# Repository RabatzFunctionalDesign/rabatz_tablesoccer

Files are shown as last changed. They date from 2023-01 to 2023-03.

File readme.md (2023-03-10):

# Rabatz Table Soccer

*Production files and assembly instructions*

## Project links

- [Design reference](https://www.rabatzdesign.com)
- [Production files](https://github.com/rabatzfunctionaldesign/rabatz_tablesoccer) _(you are here)_

## Preview

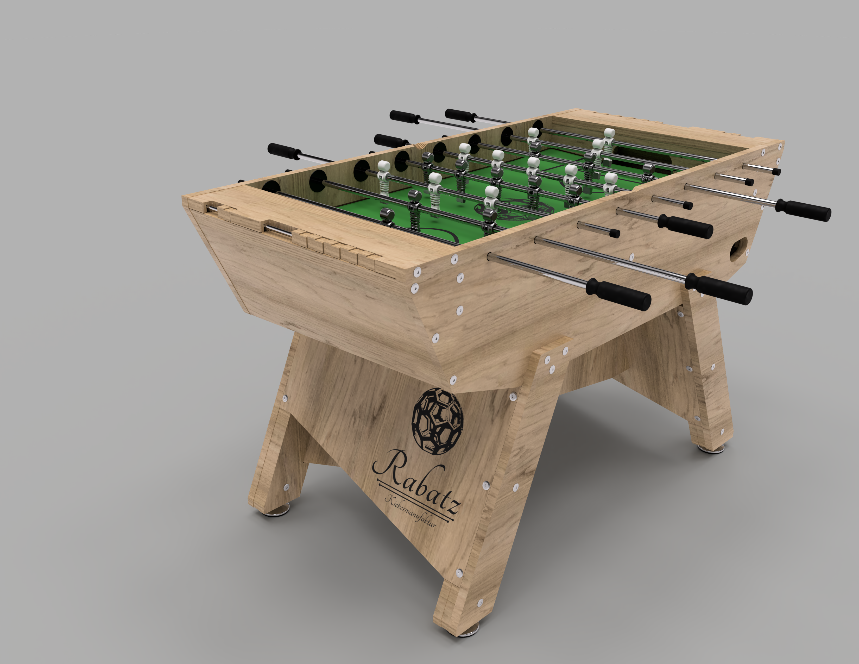
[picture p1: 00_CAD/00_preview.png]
<span></span>

## Production steps

- 00 [Base of Materials](https://github.com/RabatzFunctionalDesign/rabatz_tablesoccer/blob/main/Base_of_Materials.pdf)
- 01 CNC-milling
- 02 Surface finishing
- 03 Playing field assembly
- 04 Table soccer assembly

## Copyright & License

&copy;Andr&eacute; Mirtschink
info@rabatzdesign.com

This work is licensed under a
[Creative Commons Attribution-NonCommercial-ShareAlike 4.0 International License](http://creativecommons.org/licenses/by-nc-sa/4.0/)

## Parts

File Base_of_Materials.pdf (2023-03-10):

Base of Materials

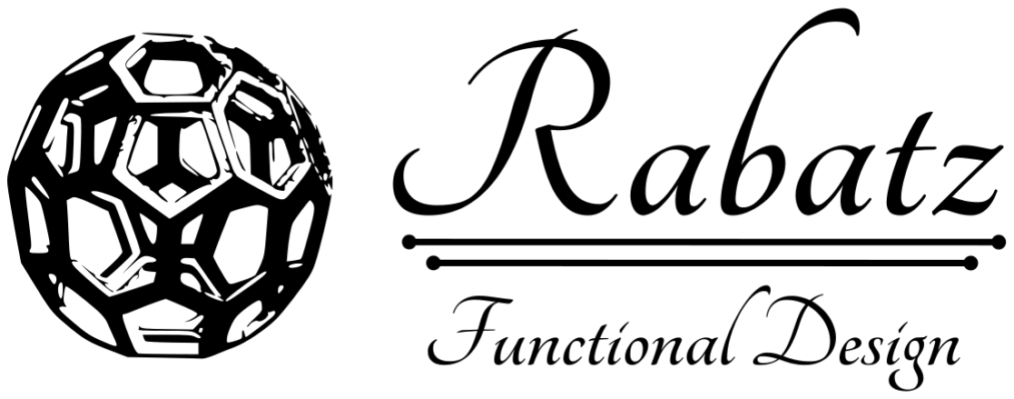
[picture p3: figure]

Pos. | Item | Quantity
1 | Table soccer ball “Contus Skill” (https://kicker-klaus.de/kicker-ball-contus-skill) | 4 Pcs
2 | Soccer player, white balanced (https://kicker-klaus.de/kicker-figur-original-soccer?farbe1=weiss&austariert=ja) | 11 Pcs
3 | Soccer player, black balanced (https://kicker-klaus.de/kicker-figur-original-soccer?farbe1=schwarz&austariert=ja) | 11 Pcs
4 | Screw “Original Soccer”, nickel (https://kicker-klaus.de/kicker-schraube-sonderform-leonhart-contus-soccer?surface=nickel) | 24 Pcs
5 | Nut “Original Soccer”, nickel (https://kicker-klaus.de/kicker-mutter-sonderform-leonhart-contus-soccer) | 24 Pcs
6 | Soccer rod “Contus L4 DTFB”, Defense (https://kicker-klaus.de/kicker-stange-contus-l4?typ=v2) | 2 Pcs
7 | Soccer rod “Contus L4 DTFB”, Goal + Attack (https://kicker-klaus.de/kicker-stange-contus-l4?typ=t3n) | 4 Pcs
8 | Soccer rod “Contus L4 DTFB”, Midfield (https://kicker-klaus.de/kicker-stange-contus-l4?typ=m5) | 2 Pcs
9 | Bearing “Contus Laser”, black matt (https://kicker-klaus.de/kicker-lager-gleit-contus-leonhart?typ=matt-schwarz) | 16 Pcs
10 | Buffer with add-on ring, L = 19 mm (https://kicker-klaus.de/kicker-puffer-gummi-luftkanal-einsteckring) | 16 Pcs
11 | Slide ring (https://kicker-klaus.de/kicker-gleitring-normal) | 16 Pcs
12 | Adjusting ring incl. Screw and nut (https://kicker-klaus.de/kicker-stellring-metall) | 4 Pcs
13 | Handle “Contus JetSpin” (https://kicker-klaus.de/kicker-griff-contus-jetspin) | 8 Pcs
14 | Playing field “Contus”, indoor (https://kicker-klaus.de/kicker-spielfeld-contus?typ=indoor) | 1 Pcs
15 | Playing field wedges (https://kicker-klaus.de/kicker-spielfeld-keile-contus) | 1 Pcs
16 | Slip agent “Contus Rapid Pur” (https://kicker-klaus.de/kicker-gleitmittel-contus-rapid-pur) | 1 Pcs
17 | Screw fladhead 8 x 50 mm (https://www.rampa.com/de/de/schrauben/115-flachkopfschrauben-typ-kf.html) | 48 Pcs
18 | Cap nut 8 x 25 mm (https://www.rampa.com/de/de/rundmuttern-quergewindebolzen/97-rundmuttern-typ-rfl.html) | 42 Pcs
19 | Set screw 8 x 60 mm | 20 Pcs
20 | Slide nut 25 x 13 x 6 mm (https://www.sorotec.de/shop/Gleitmutter-25-x-13-x-6-mm-Gewinde-M8--20-Stueck.html?language=de) | 48 Pcs
21 | Screw Torx 3 x 25 mm (https://www.schraubenluchs.de/200-Stueck-ABC-Spax-A2-Vollgewinde-Torx-3x25-mm) | 75 Pcs
22 | Round bar inox, D = 8 mm (https://www.stahl-shop24.de/Edelstahl-Rundstab-8mm-1000mm) | 1.5 m
23 | Threaded rod, D = 8 mm (https://www.schraubenluchs.de/1-Stk-Gewindestange-DIN-975-46-verzinkt-M8-Linksgewinde) | 0.8 m
24 | Contact adhesive 300 g (https://www.pattex.de/de/products/klebstoff/kraftkleber/kraftkleber_classic.1419336.html#variants) | 1 Pcs
25 | Dowel, 8 x 40 mm (https://www.contorion.de/p/bosch-holzduebel-8-mm-40-mm-c89767148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) | 8 Pcs
- 1 -

Base of Materials

Pos. | Item | Quantity
26 | Protection Goalpost (https://a360.co/3ZXgQlr) | 4 Pcs
27 | Silicone round cord, D = 8 mm (https://www.haustechnik-express.de/gasoel-feuerungstechnik-abgas-kamin-zubehoer-dichtschnre-silikondichtschnur-rund-laenge-p-6683.html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) | 3 m
28 | Leveling feet, stainless steel (https://norelem.de/de/Produkt%C3%BCbersicht/Systeme-und-Komponenten-f%C3%BCr-den-Maschinen-und-Anlagebau/27000/Stellf%C3%BC%C3%9Fe-Maschinenf%C3%BC%C3%9Fe/Ste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) | 4 Pcs
29 | Connection nut 12 x 50 mm (https://www.schraubenluchs.de/25-Stueck-Verbindungsmuttern-Sechskant-galv-verzinkt-M12-x-50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) | 4 Pcs
30 | Birch Plywood 2500 x 1250 x 24 mm (http://www.rabatzdesign.com) | 2 Pcs
31 | Medium dense fiber board 1200 x 700 x 19 mm (http://www.tagwerk.space) | 1 Pcs
32 | Hard oil transparent 0.75 L (https://shop.streichgut.com/streichgutoele11/oel/4681/hartoel-farblos11?number=STG-425.2&c=216) | 1 Pcs
33 | Hard wax transparent 0.075 kg (https://shop.streichgut.com/farben/hartoel/4602/hartwachs11?c=214) | 1 Pcs
- 2 -

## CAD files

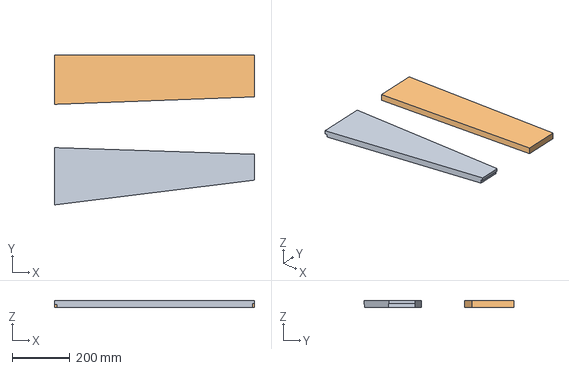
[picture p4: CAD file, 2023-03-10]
00_CAD/Ramps.3mf
694.0 x 519.9 x 25.0 mm
Körper1 x 2

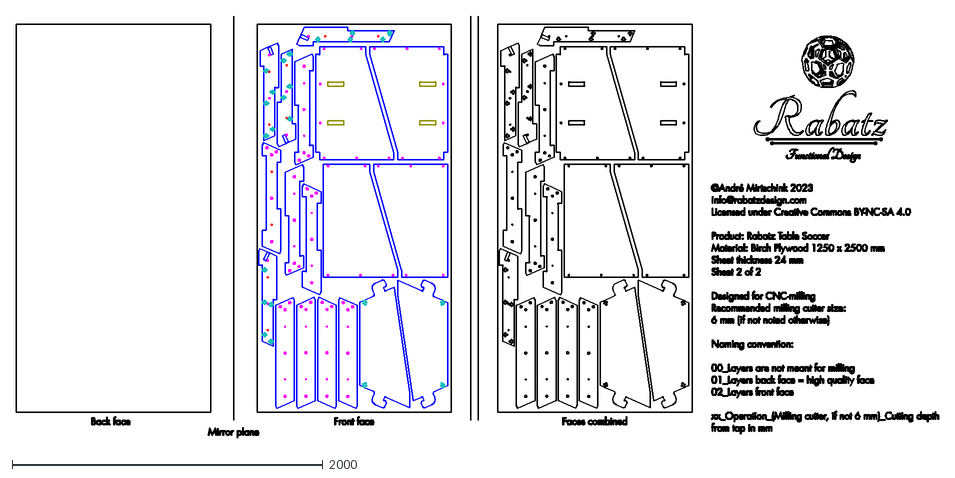
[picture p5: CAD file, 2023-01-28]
01_Milling/01_Milling_2o2.dxf
5937.6 x 2713.2

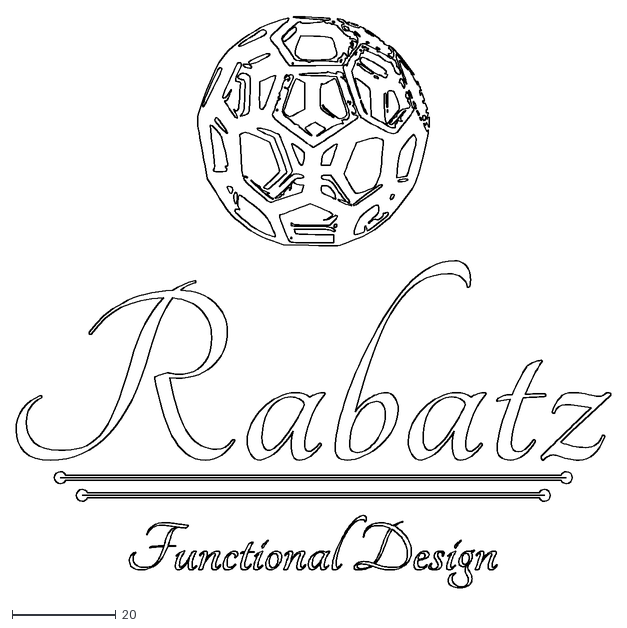
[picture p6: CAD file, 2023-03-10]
02_Surface/02_logo.dxf
114.6 x 110.1

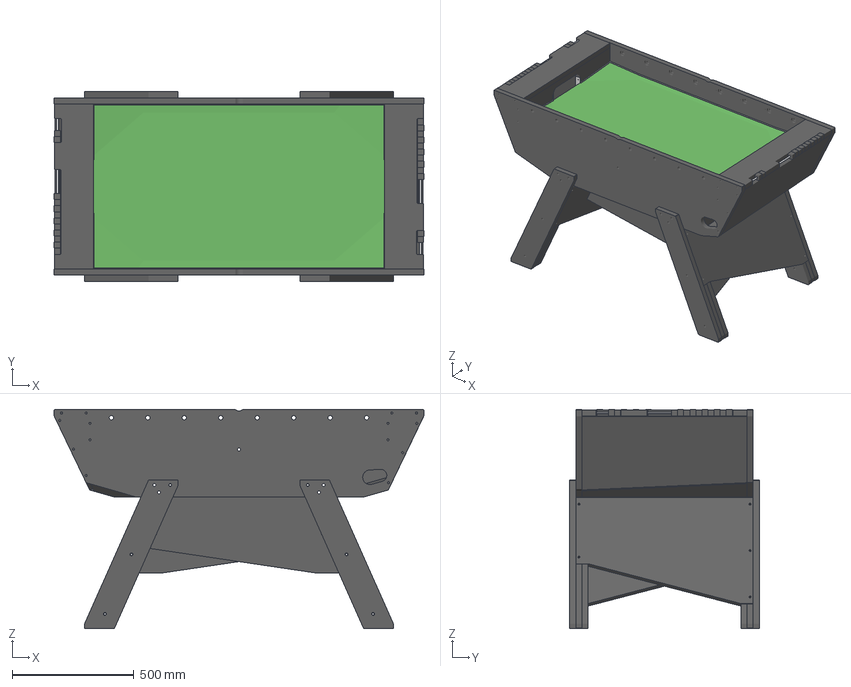
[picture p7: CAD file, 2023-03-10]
00_CAD/RabatzTableSoccer.3mf
1522.0 x 780.0 x 901.0 mm
Körper1 x 58
Körper2 x 5
Körper3 x 2
Körper4 x 2
Körper43
Körper5 x 2
Körper50
Körper6
Körper7
Körper8

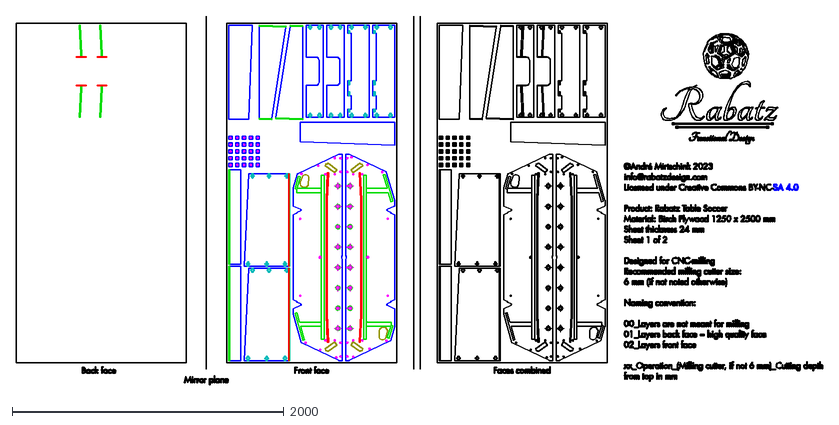
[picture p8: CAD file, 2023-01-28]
01_Milling/01_Milling_1o2.dxf
5937.6 x 2713.2

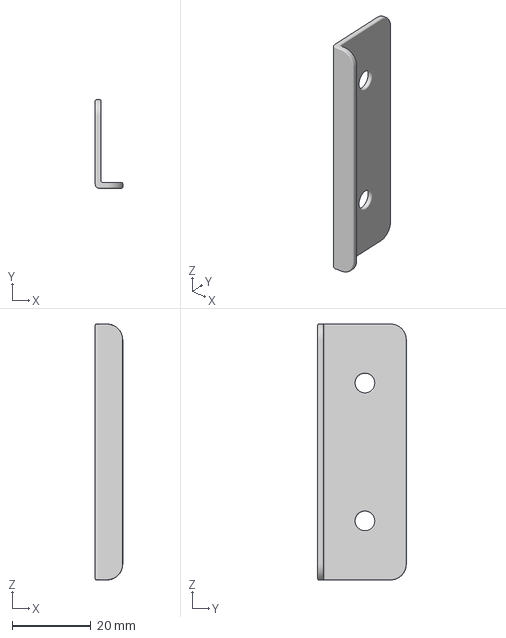
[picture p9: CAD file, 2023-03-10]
00_CAD/Goalpost.3mf
7.00 x 22.5 x 65.0 mm

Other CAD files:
00_CAD/Goalpost.dwg
00_CAD/Goalpost.dxf
00_CAD/Goalpost.f3d
00_CAD/Goalpost.obj
00_CAD/Goalpost.stl
00_CAD/RabatzTableSoccer.dwg
00_CAD/Ramps.dwg
00_CAD/Ramps.dxf
00_CAD/Ramps.f3d
00_CAD/Ramps.obj
00_CAD/Ramps.stl

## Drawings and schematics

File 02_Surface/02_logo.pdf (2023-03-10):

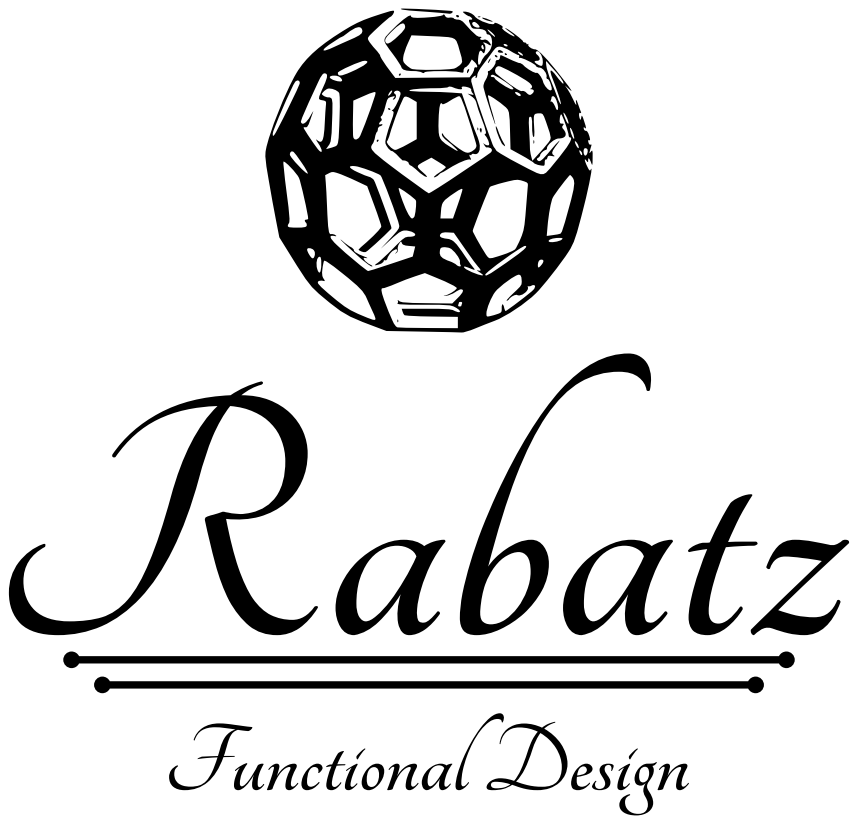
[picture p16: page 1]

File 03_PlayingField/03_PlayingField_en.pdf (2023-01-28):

z

# aR bat

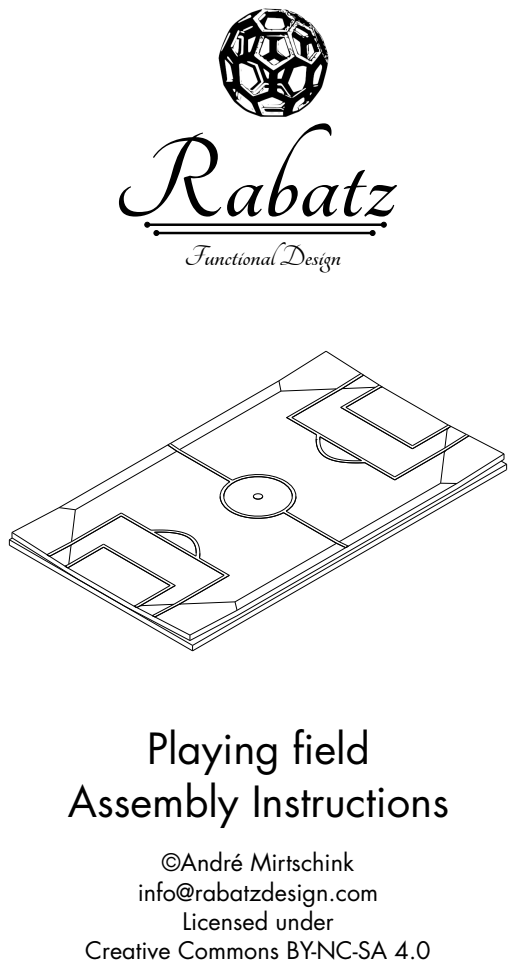
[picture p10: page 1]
Functional Design; Playing field Assembly Instructions

©André Mirtschink
info@rabatzdesign.com
Licensed under

Creative Commons BY-NC-SA 4.0

z

# aR bat

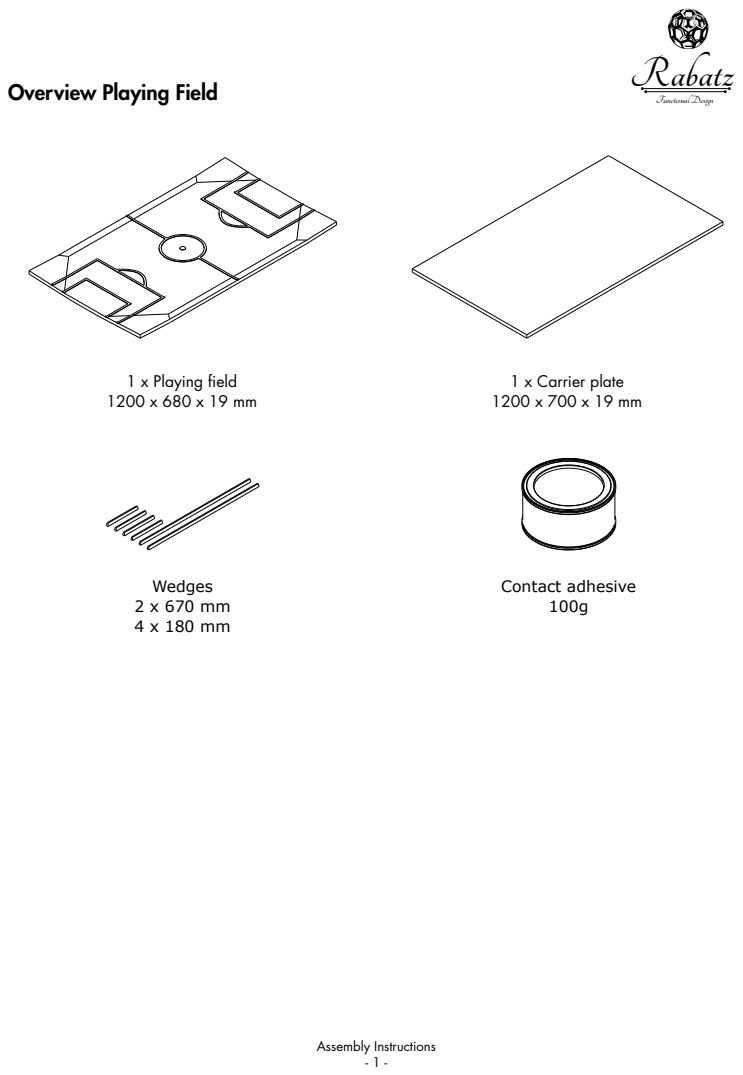
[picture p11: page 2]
Functional Design; Assembly Instructions - 1 -; 1 x Playing field 1200 x 680 x 19 mm; 1 x Carrier plate 1200 x 700 x 19 mm; Wedges 2 x 670 mm 4 x 180 mm; Contact adhesive 100g

Overview Playing Field

z

# aR bat

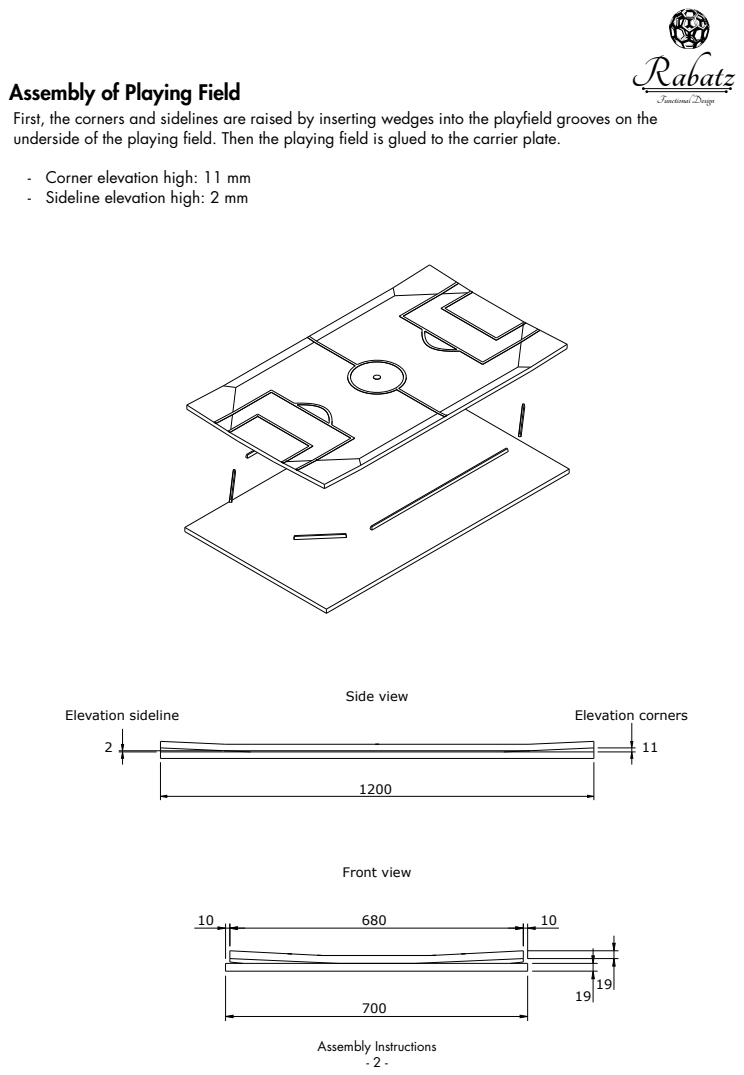
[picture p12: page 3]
Functional Design; Assembly Instructions - 2 -; Elevation sideline; Elevation corners; Side view; Front view

Assembly of Playing Field
First, the corners and sidelines are raised by inserting wedges into the playfield grooves on the
underside of the playing field. Then the playing field is glued to the carrier plate.

- Corner elevation high: 11 mm
- Sideline elevation high: 2 mm

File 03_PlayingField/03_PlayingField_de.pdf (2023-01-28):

z

# aR bat

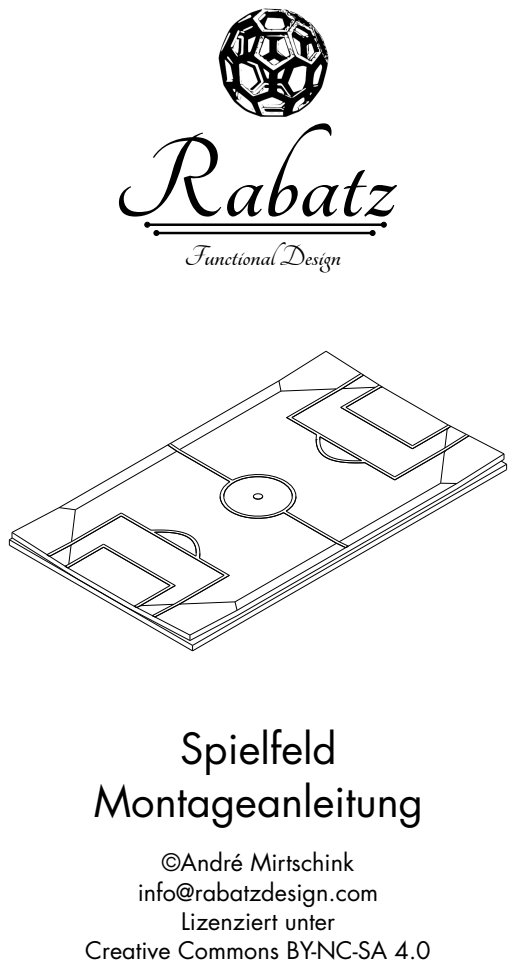
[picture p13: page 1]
Functional Design; Spielfeld Montageanleitung; ©André Mirtschink a

info@rabatzdesign.com
Lizenziert unter

Creative Commons BY-NC-SA 4.0

z

# aR bat

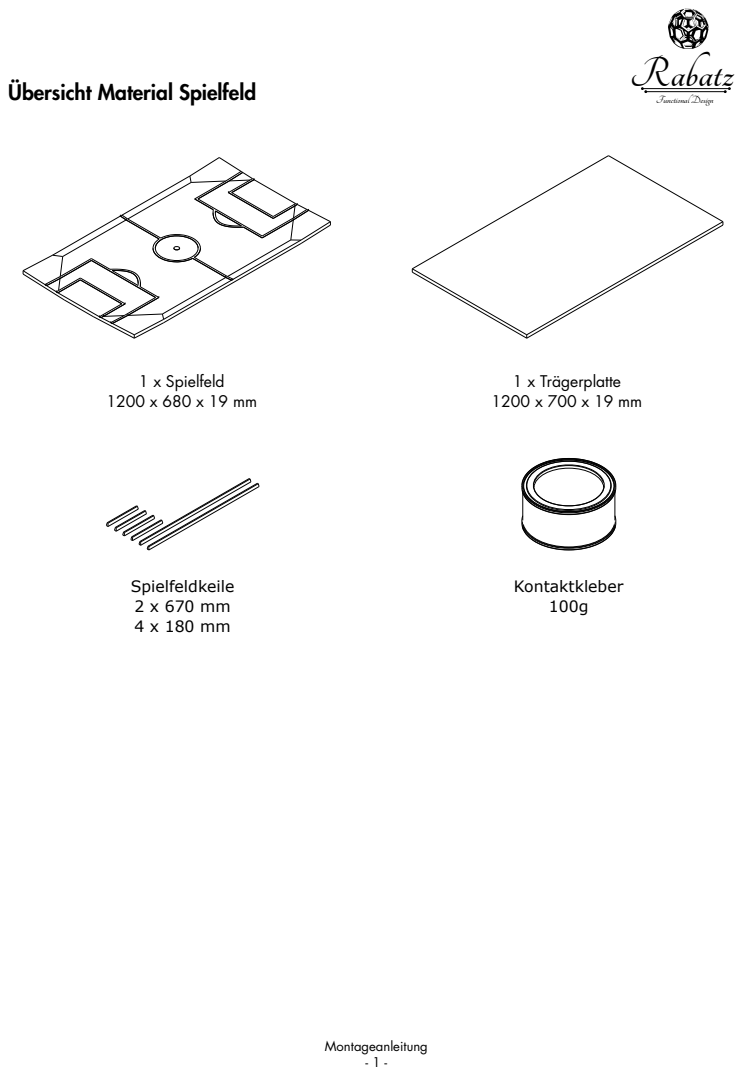
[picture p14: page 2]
Functional Design; Montageanleitung - 1 -; 1 x Spielfeld 1200 x 680 x 19 mm; 1 x Trägerplatte 1200 x 700 x 19 mm; Spielfeldkeile 2 x 670 mm 4 x 180 mm; Kontaktkleber 100g

Übersicht Material Spielfeld

z

# aR bat

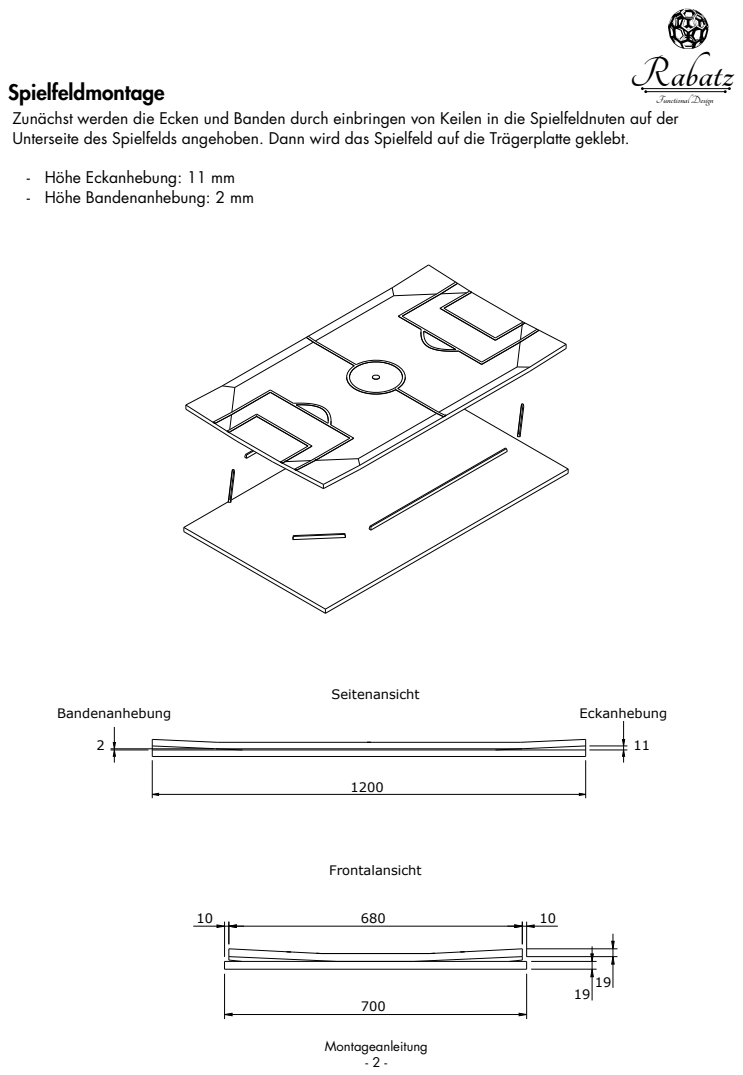
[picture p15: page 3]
Functional Design; Montageanleitung - 2 -; Bandenanhebung; Eckanhebung; Seitenansicht; Frontalansicht

Spielfeldmontage
Zunächst werden die Ecken und Banden durch einbringen von Keilen in die Spielfeldnuten auf der
Unterseite des Spielfelds angehoben. Dann wird das Spielfeld auf die Trägerplatte geklebt.

- Höhe Eckanhebung: 11 mm
- Höhe Bandenanhebung: 2 mm
